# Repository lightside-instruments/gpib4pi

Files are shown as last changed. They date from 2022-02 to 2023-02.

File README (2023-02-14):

The gpib4pi project is open hardware design of a Raspbery Pi
extension board with GPIB interface using only GPIOs.

The project includes schematics and PCB
design files for KiCAD. The board can be used with
the linux-gpib software tools and the gpib_bitbang.ko
driver.

The project is published by Lightside Instruments AS
under TAPR Open Hardware License. Read the LICENSE file
for details.

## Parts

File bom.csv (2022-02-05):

Reference | Quantity | Identifier | footprint | Value | Tolerance | Voltage | Current | Power | PN
J2 | 1 |  | ice4pi:PinSocket_2x20_P2.54mm_Vertical_1_04mm | Raspberry_Pi_2_3 |  |  |  |  | SSW-120-01-T-D-006
J3 | 1 |  | ice4pi:centronix-24-male | Conn_02x12_Top_Bottom |  |  |  |  | 112-024-113R001
U6 | 1 |  | Package_DIP:DIP-20_W7.62mm | SN75160BN |  |  |  |  | SN75160BN
U7 | 1 |  | Package_DIP:DIP-20_W7.62mm | SN75161BN |  |  |  |  | SN75161BN
R111-R118;R211-R218 | 16 |  | Resistor_SMD:R_0402_1005Metric | 3.3K |  |  |  |  | RC0402JR-073K3L
R121-R128;R221-R228 | 16 |  | Resistor_SMD:R_0402_1005Metric | 6.2K |  |  |  |  | RC0402FR-076K2L
C33,C34 | 2 |  | Capacitor_SMD:C_0402_1005Metric | 220nF |  |  |  |  | GRM155C8YA224KE01J
C7 | 1 |  | Capacitor_SMD:C_0402_1005Metric | 10uF |  |  |  |  | ZRB15XR61A106ME01D
R3,R4 | 2 |  | Resistor_SMD:R_0402_1005Metric | 1K |  |  |  |  | ERJ-2GEJ102X
D7 | 1 |  | Diode_SMD:D_0603_1608Metric | ACTIVE_LED_GREEN |  |  |  |  | 150060VS55040
D8 | 1 |  | Diode_SMD:D_0603_1608Metric | POWER_LED_RED |  |  |  |  | 150060RS55040

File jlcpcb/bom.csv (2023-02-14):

Comment | Designator | Footprint | JLCPCB Part #（optional）
3.3K | R111,R112,R113,R114,R115,R116,R117,R118,R211,R212,R213,R214,R215,R216,R217,R218 | R0402 | C25890
6.2K | R121,R122,R123,R124,R125,R126,R127,R128,R221,R222,R223,R224,R225,R226,R227,R228 |  | C325566
GRM155C8YA224KE01J | C33,C34 | Capacitor_SMD:C_0402_1005Metric | C16772
ZRB15XR61A106ME01D | C7 | Capacitor_SMD:C_0402_1005Metric | C527590
ERJ-2GEJ102X | R3,R4 | Resistor_SMD:R_0402_1005Metric | C11702
150060VS55040 | D7 | Diode_SMD:D_0603_1608Metric | C72043
150060RS55040 | D8 | Diode_SMD:D_0603_1608Metric | C2286
SSW-120-01-T-D-006 | J2 | ice4pi:PinSocket_2x20_P2.54mm_Vertical_1_04mm | C35165
112-024-113R001 | J3 | ice4pi:centronix-24-male
SN75160BN | U6 | Package_DIP:DIP-20_W7.62mm | C2328
SN75161BN | U7 | Package_DIP:DIP-20_W7.62mm | C2328

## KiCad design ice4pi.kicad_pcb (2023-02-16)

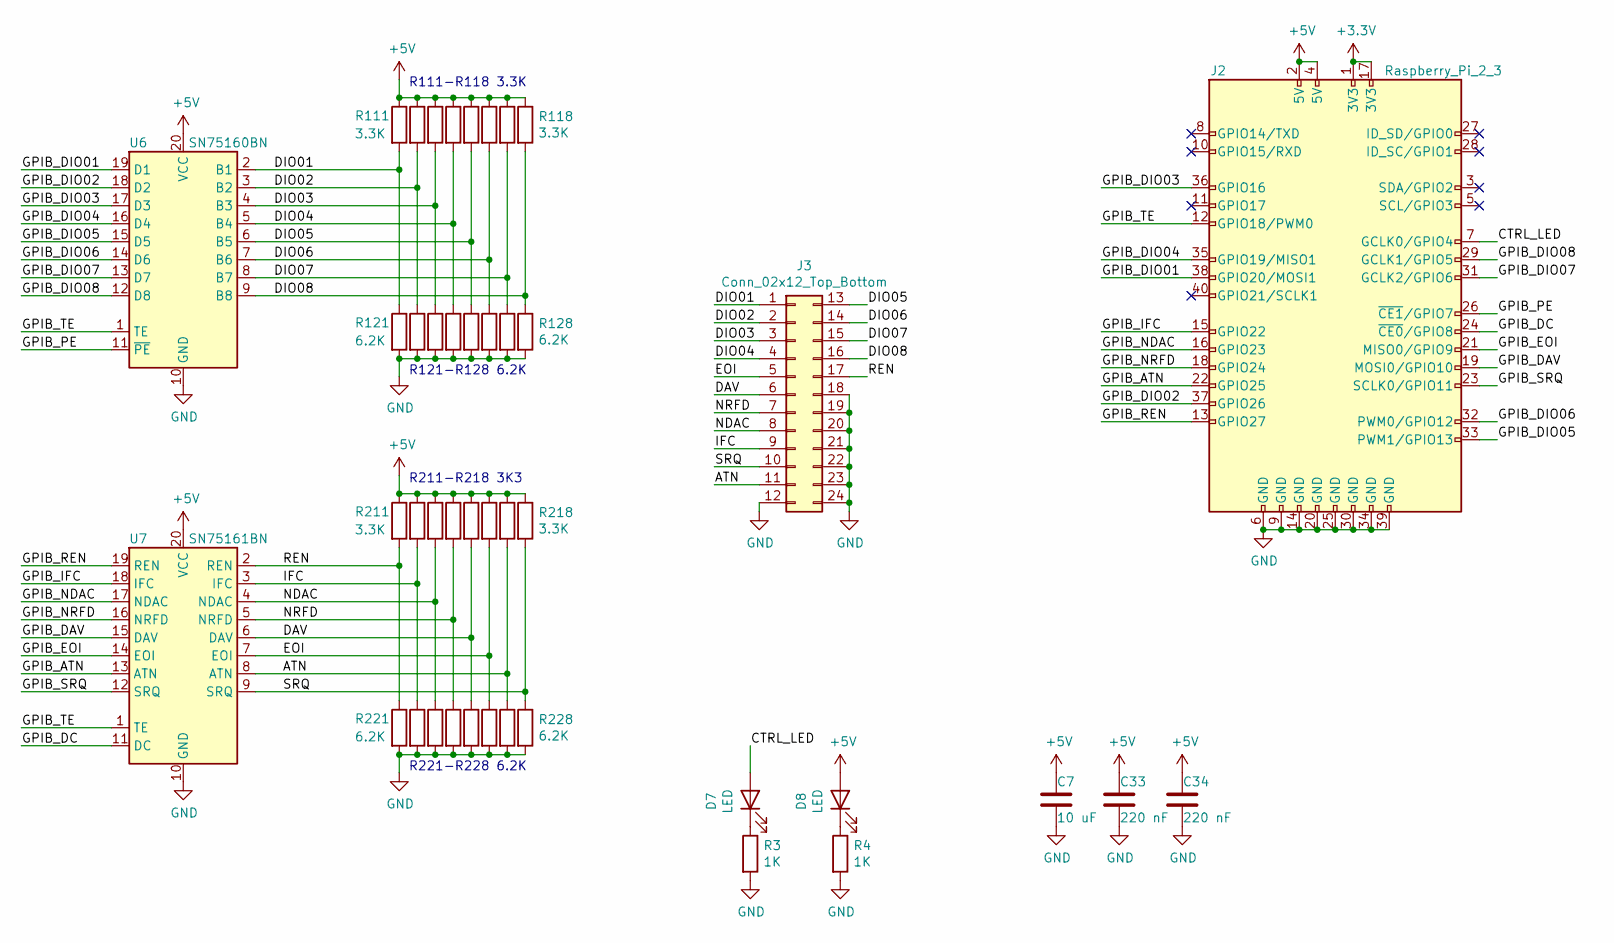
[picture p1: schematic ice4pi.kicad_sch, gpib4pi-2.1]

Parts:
C7: 10 uF; C_0402_1005Metric
C33, C34: 220 nF; C_0402_1005Metric
D7, D8: LED; LED_0603_1608Metric
J2: Raspberry_Pi_2_3; PinSocket_2x20_P2.54mm_Vertical_1_04mm
J3: Conn_02x12_Top_Bottom; centronix-24-male
R3, R4: 1K; R_0402_1005Metric
R111, R112, R113, R114, R115, R116, R117, R118, R211, R212, R213, R214, R215, R216, R217, R218: 3.3K; R_0402_1005Metric
R121, R122, R123, R124, R125, R126, R127, R128, R221, R222, R223, R224, R225, R226, R227, R228: 6.2K; R_0402_1005Metric
U6: SN75160BN; DIP-20_W7.62mm
U7: SN75161BN; DIP-20_W7.62mm

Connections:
+3.3V: J2.1 (3V3), J2.17 (3V3)
+5V: C7.1, C33.1, C34.1, D8.2 (A), J2.2 (5V), J2.4 (5V), R111.1, R112.1, R113.1, R114.1, R115.1, R116.1, R117.1, R118.1, R211.1, R212.1, R213.1, R214.1, R215.1, R216.1, R217.1, R218.1, U6.20 (VCC), U7.20 (VCC)
/ATN: J3.11, R217.2, R227.1, U7.8 (ATN)
/CTRL_LED: D7.2 (A), J2.7 (GCLK0/GPIO4)
/DAV: J3.6, R215.2, R225.1, U7.6 (DAV)
/DIO01: J3.1, R111.2, R121.1, U6.2 (B1)
/DIO02: J3.2, R112.2, R122.1, U6.3 (B2)
/DIO03: J3.3, R113.2, R123.1, U6.4 (B3)
/DIO04: J3.4, R114.2, R124.1, U6.5 (B4)
/DIO05: J3.13, R115.2, R125.1, U6.6 (B5)
/DIO06: J3.14, R116.2, R126.1, U6.7 (B6)
/DIO07: J3.15, R117.2, R127.1, U6.8 (B7)
/DIO08: J3.16, R118.2, R128.1, U6.9 (B8)
/EOI: J3.5, R216.2, R226.1, U7.7 (EOI)
/GPIB_ATN: J2.22 (GPIO25), U7.13 (ATN)
/GPIB_DAV: J2.19 (MOSI0/GPIO10), U7.15 (DAV)
/GPIB_DC: J2.24 (~CE0/GPIO8), U7.11 (DC)
/GPIB_DIO01: J2.38 (GPIO20/MOSI1), U6.19 (D1)
/GPIB_DIO02: J2.37 (GPIO26), U6.18 (D2)
/GPIB_DIO03: J2.36 (GPIO16), U6.17 (D3)
/GPIB_DIO04: J2.35 (GPIO19/MISO1), U6.16 (D4)
/GPIB_DIO05: J2.33 (PWM1/GPIO13), U6.15 (D5)
/GPIB_DIO06: J2.32 (PWM0/GPIO12), U6.14 (D6)
/GPIB_DIO07: J2.31 (GCLK2/GPIO6), U6.13 (D7)
/GPIB_DIO08: J2.29 (GCLK1/GPIO5), U6.12 (D8)
/GPIB_EOI: J2.21 (MISO0/GPIO9), U7.14 (EOI)
/GPIB_IFC: J2.15 (GPIO22), U7.18 (IFC)
/GPIB_NDAC: J2.16 (GPIO23), U7.17 (NDAC)
/GPIB_NRFD: J2.18 (GPIO24), U7.16 (NRFD)
/GPIB_PE: J2.26 (~CE1/GPIO7), U6.11 (~PE)
/GPIB_REN: J2.13 (GPIO27), U7.19 (REN)
/GPIB_SRQ: J2.23 (SCLK0/GPIO11), U7.12 (SRQ)
/GPIB_TE: J2.12 (GPIO18/PWM0), U6.1 (TE), U7.1 (TE)
/IFC: J3.9, R212.2, R222.1, U7.3 (IFC)
/NDAC: J3.8, R213.2, R223.1, U7.4 (NDAC)
/NRFD: J3.7, R214.2, R224.1, U7.5 (NRFD)
/REN: J3.17, R211.2, R221.1, U7.2 (REN)
/SRQ: J3.10, R218.2, R228.1, U7.9 (SRQ)
GND: C7.2, C33.2, C34.2, J2.6 (GND), J2.9 (GND), J2.14 (GND), J2.20 (GND), J2.25 (GND), J2.30 (GND), J2.34 (GND), J2.39 (GND), J3.12, J3.18, J3.19, J3.20, J3.21, J3.22, J3.23, J3.24, R3.2, R4.2, R121.2, R122.2, R123.2, R124.2, R125.2, R126.2, R127.2, R128.2, R221.2, R222.2, R223.2, R224.2, R225.2, R226.2, R227.2, R228.2, U6.10 (GND), U7.10 (GND)
unnamed: D7.1 (K), R3.1
unnamed: D8.1 (K), R4.1

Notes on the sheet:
R111-R118 3.3K
R121-R128 6.2K
R211-R218 3K3
R221-R228 6.2K

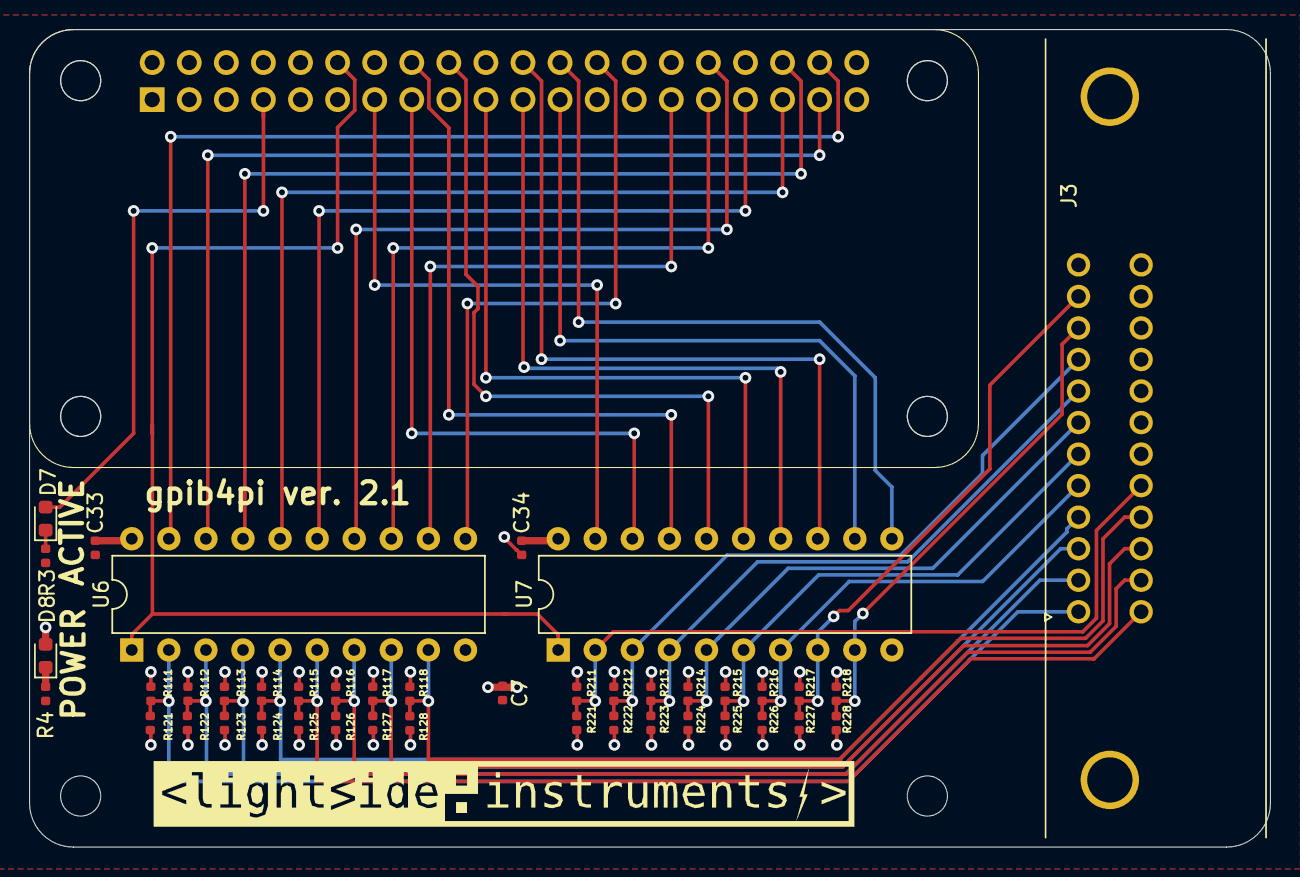
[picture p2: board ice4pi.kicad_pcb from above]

Board: 4 copper layers, 85.0 x 56.0 mm, 44 parts (1 on the bottom side), 41 nets.

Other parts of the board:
svg2mod: G***; lsi-logo-48mm

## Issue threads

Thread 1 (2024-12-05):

Add pull up resistors to GPIB_DAV, GPIB_NRFD and GPIB_NDAC

gmgeronymo, 2024-12-05:
Hi,

I built some boards on jlpcb using your design. In my application I need to drive a GPIB bus with 5 or 6 devices, so I need to use the SN7516x drivers ICs. I was facing some GPIB read errors, and after some debugging and testing, I found that adding 10 k resistors pulling GPIB_DAV, GPIB_NRFD and GPIB_NDAC to 3.3 V, just like the original elektronomikon design (https://raw.githubusercontent.com/elektronomikon/raspi_gpib_shield/master/Documentation/RPi_GPIB_Shield.pdf), the board works perfectly. Is there any reason to remove those resistor on your design? Otherwise, I would suggest to add them for a more reliable operation.

Thanks and best regards,

Gean

lightside-instruments, 2024-12-07:
Hi,

What kind of driver and Raspberry Pi combination are you experiencing problems with? We have not experienced GPIB read errors on any of the deployments and we do communicate with various acquisition devices and generators so bidirectional heavy traffic in long periods.

The DAV NRFD and NDAC are changing direction but so do D0-D7. Why would be those pull-ups be necessary only on the handshake pins?

If it turns out that for some model of Raspberry Pi there is a need for pull-ups I would rather add pull-ups to all the pins since input drivers are identical.

/V

gmgeronymo, 2024-12-08:
Hi,

I used SN75160BN and SN75161BN ICs from aliexpress as drivers. My tests were done using Raspberry Pi A+ and Raspberry Pi 3 B (the older version, not B+).
I got the GPIB read errors when trying to get data from Keithley 182 and 2182A nanovoltmeters.
I also built the more simpler version of the circuit, using just 100 ohm series resistores in a protoboard, without any pull up / pull down resistors. It worked, but only up to four GPIB devices.

lightside-instruments, 2024-12-10:
Are the SN75160BN and SN75161BN ICs from aliexpress the actual TI chips or is it possible they are behaving differently. I know the TI ones have a pull-up current which is less then a 10K ohm pullup would give but significant enough for the inputs to operate without problem.

lightside-instruments, 2025-01-30:
The documentation of the bus transceivers https://www.ti.com/lit/ds/symlink/sn75161b.pdf states that on the terminal side they are all 3-state outputs and not passive-pullup. With maximum high-level output current of -800 uA and low-level output current of 16 mA. All of the 16 terminal lines are identical. There is no recommendation for pull-ups to be used or any differentiation to justify it is used on only 3 of the  lines (GPIB_DAV, GPIB_NRFD and GPIB_NDAC) instead on all of them. I have not received any reports of signal integrity errors with the original SN75160BN and SN75161BN transceivers (from TI).

fig.5 shows that close to -16mA can be sourced from the terminal pins to hold high-level at almost 2V (lower then the nominal 3.5 volts) which is still high-level and the current is significantly higher then the -800 uA and makes for a symmetrical push-pull output driver that does not need pullup.

At this point I am not willing to make modification to the board to make it work with undocumented aliexpress drivers that seem to require them and adding unnecessary components increasing capacitance and susceptibility to noise interception when the original drivers are used.

Still it would be interesting to find what was the logic behind adding the pullups in the elektronomikron board was.

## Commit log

2020-01-29 Release ice4pi-1.0
    [ice4pi.kicad_pcb, ice4pi.sch]
2020-02-14 Release ice4pi-1.1
    [bom.csv, ice4pi.kicad_pcb, ice4pi.sch]
2021-01-29 Release 1.2
    [ice4pi.kicad_pcb, ice4pi.sch]
2022-02-04 Release ice4pi-gpib-1.0
    [bom.csv, ice4pi.kicad_pcb, ice4pi.sch]
2022-02-05 Release gpib4pi-1.0
    [bom.csv, ice4pi.kicad_pcb, ice4pi.sch]
2022-08-08 Release gpib4pi-1.1
    [ice4pi.kicad_pcb, ice4pi.sch]
2023-02-14 Release gpib4pi-1.2
    [bom.csv, ice4pi.kicad_pcb, ice4pi.kicad_sch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]
2023-02-14 Release gpib4pi-2.0
    [ice4pi.kicad_pcb, ice4pi.kicad_sch]
2023-02-16 Release gpib4pi-2.1
    [ice4pi.kicad_pcb, ice4pi.kicad_sch]
